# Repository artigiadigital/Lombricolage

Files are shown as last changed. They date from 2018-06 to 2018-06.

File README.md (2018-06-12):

# Lombricolage

## MINI COMPOSTATORE DI FONDI DI CAFFÈ
## ISTRUZIONI PER L'USO E STORIA DEL TAMAGOTCHI DELL'ECONOMIA CIRCOLARE

### CHE COSA È IL LOMBRICOLÀGE?
Il Lombricolàge è un minicompostatore in bioplastica (PLA - Acido Polilattico) stampato in 3D che,
utilizzando alcune specie di lombrichi, è in grado di produrre un compost (vermicompost) di altissima
qualità partendo dai fondi di caffè. La bioplastica è prodotta utilizzando scarti vegetali quindi senza
l'impiego di petrolio e può essere compostata a sua volta, ma a temperature e condizioni diverse da quelle
dell'uso del compostatore che , in condizioni di normale temperatura e umidità, è stabile.
### COME SI USA?
Il Lombricolàge nella sua versione base ha due moduli cilindrici. Si inizia inserendo nel modulo superiore i
lombrichi (almeno per iniziare una decina, meglio ancora per avviare la coltura un quarto in volume di uno
dei due moduli) della specie Eisenia fetida o Eisenia andrei insieme ai fondi di caffè, sbriciolandoli a
mano o con la paletta in dotazione o, nel caso delle cialde, liberandole dall'involucro. Quando il modulo
superiore è pieno, si possono invertire i moduli (spostando il superiore in basso e l'inferiore vuoto in alto).
I fondi di caffè vanno innaffiati quando si seccano in modo che il contenuto sia sempre leggermente
umido, ma mai zuppo. Per innaffiare il contenuto in maniera uniforme potete usare la cupola rovesciata.
### DOVE SI TIENE IL LOMBRICOLÀGE?
I lombrichi Eisenia si trovano a loro agio all'ombra e in un intervallo tra i 13°C e i 25°C, sopravvivono
dagli 0°C ai 35°C seppur riducendo molto la loro attività e quindi il processo di compostaggio del caffè.
Anche la bioplastica con cui è realizzato il Lombricolàge è sensibile al calore e alla luce diretta
continuativa del sole. Se avrete cura della bioplastica, non solo il Lombricolàge non si deformerà, ma i
lombrichi rimarranno in salute. Considerateli un tutt'uno e come se fossero un sistema vivente. I lombrichi
non escono comunque mai dal Lombricolàge poiché per loro è un ambiente ideale, pertanto non abbiate timore: non li troverete in giro per casa.
### IN QUANTO TEMPO SI FORMA IL COMPOST?
Il tempo di compostaggio a regime è variabile a seconda della stagione, e quindi delle temperature, dai 2 ai
4 mesi. Potete constatare che il processo è completato nel momento in cui i fondi di caffè cominciano a
odorare di bosco. Potete rigirare regolarmente il compost con la paletta in dotazione. Anche se ha le punte
appositamente arrotondate, usatela con delicatezza per non ferire i lombrichi.
### E QUANDO IL COMPOST E' PRONTO?
Potete mischiarlo al terriccio per le vostre piante, anche insieme ai lombrichi che continueranno pertanto la
loro azione benefica per le fertilità del suolo anche fuori dal Lombricolàge, ma conservatene sempre un
certo quantitativo per rimetterli nei moduli intermedi e continuare il processo. Se invece desiderate
dividere il compost dai lombrichi per conservarne il maggior numero possibile, potete farlo manualmente
oppure potete rovesciare il contenuto di un modulo all'interno di una piccola vaschetta o barattolo, e
riempire lentamente di acqua fino a lasciare circa 3 centimetri di compost fuori dall'acqua. I lombrichi nel
giro di 10-20 minuti si sposteranno da soli verso la parte emersa. Con la paletta in dotazione, o un
cucchiaio, potete quindi separarli dal materiale sottostante in immersione e riporli nel Lombricolàge. La
parte che rimarrà sotto il pelo dell'acqua sarà un misto di compost, qualche lombrico più pigro a scappare e
acqua. Dividete quindi il compost dall'acqua con un mestolo o filtrandolo. Potete usare il compost e i
lombrichi mischiandoli alla terra dei vasi. L'acqua rimanente, che sarà diventata un liquido scuro, è un
fertilizzante molto potente, quindi non gettatelo: potete usarlo per innaffiare previa ampia diluizione.
### POSSONO CAPITARE INCONVENIENTI ?
Se la superficie superiore del caffè presenta muffe, non preoccupatevi: basta girarlo con la paletta ed
evitare che sia o troppo secco o troppo umido. Può capitare che si formino dei moscerini (neri o bianchi):
non usate assolutamente insetticidi, ma rigirate i fondi di caffè con la paletta, riducete le innaffiature e
all'occorrenza lasciate per qualche giorno il Lombricolàge senza la cupola per farlo asciugare un pochino.
Verificate in ogni caso che la base inferiore non abbia conservato troppa acqua. Anche in questo caso può
essere usata come fertilizzante. Nei mesi più caldi, o in caso di assenza prolungata da casa, potete anche
lasciare un dito di acqua nel serbatoio per evitare che i fondi si secchino troppo. I lombrichi sopravvivono
tranquillamente in vostra assenza fino a circa 3-4 settimane. Prima di partire per più di una settimana
rigirate sempre il contenuto dei moduli intermedi, aggiungete qualche fondo di caffè per fornire nutrimento
e inumidite con acqua. I due moduli sono altamente traspiranti, caratteristica che permette all'ossigeno di
passare attraverso le loro pareti impedendo fenomeni di anossia ai lombrichi e al contenuto organico. La
traspirabilità è permessa dalla porosità dei moduli intermedi. Per tale motivo, in caso in cui si dovessero
sporcare esternamente si consiglia di lavarli subito in modo che non si macchino. Non immergete in acqua
i moduli con il compost perché rischiate anche in questo caso di inzupparne il contenuto che macchierebbe
le pareti dei moduli.
### COME E' NATO IL LOMBRICOLÀGE?
Dopo un corso di autocostruzione di stampante 3D durato un weekend ci siamo trovati come rifiuto decine
e decine di cialde di caffè (quelle in tessuto). Praticando il compostaggio domestico da anni mi sono posto
il problema di come gestire questa potenziale ricchezza organica senza doverla buttare. Avendo appenaacquisito le conoscenze basilari per il disegno CAD e già sperimentato in terrazza il compostaggio dei
fondi di caffè con lombrichi, mi sono chiesto se il processo avesse funzionato anche in un ambiente più
piccolo. Avevo in quel momento una stampante 3D appena assemblata, quale migliore occasione per dare
seguito alla teoria se non provare a realizzare un piccolo compostatore di aspetto gradevole e verificarne il
funzionamento? Dopo un anno di sperimentazione abbiamo visto che i lombrichi Eisenia fetida ed andrei,
anche se nutriti solo a fondi di caffè e in un ambiente molto piccolo (15 cm di diametro e 8 di altezza), non
solo producono un ottimo compost, ma rimangono vitali e fecondi.
### MA IN FONDO NE VALE LA PENA?
Nei soli Stati Uniti si producono 2 milioni di tonnellate all'anno di fondi di caffè che, o vanno in discarica,
o devono essere processate. Con il Lombricolàge potete produrre voi stessi in casa e in ufficio piccoli
quantitativi di compost di altissima qualità per il vostri vasi. Di certo non pensiamo di risolvere con il
Lombricolàge il problema della corretta gestione dei rifiuti urbani, ma anche i piccoli passi sono
importanti. Come è importante sopratutto nei confronti delle nuove generazioni il carattere educativo dei
concetti base dell'economia circolare e dei processi naturali del ciclo dei nutrienti. Il Lombricolàge è di
certo un ottimo ausilio didattico nelle scuole e nelle famiglie. I bambini lo adorano. Provare per credere!
Se volete saperne di più, in fondo a questo documento potete trovare alcune referenze scientifiche relative
al compostaggio del caffè e di altri rifiuti organici.
### POSSO INSERIRE NEL LOMBRICOLÀGE ANCHE ALTRO MATERIALE ORGANICO OLTRE AL CAFFÈ?
Potenzialmente sì, i lombrichi riescono a processare molti tipi di materiale organico, ma si sconsiglia di
usare pasta, pane, agrumi, carne, latticini o comunque materiale oleoso. Inoltre va tenuto in considerazione
che il volume del Lombricolàge è molto ridotto e potrebbero facilmente crearsi squilibri e formazione di
cattivi odori. Potete inserire piccoli quantitativi di carta e residui vegetali: ma non teneteli in superficie. In
ogni caso il funzionamento corretto del Lombricolàge è stato testato finora solo con i fondi di caffè.
### VORREI USARE IL LOMBRICOLÀGE PER COMPOSTARE IL MIO UMIDO DI CASA, NE SONO PREVISTE VERSIONI PIÙ GRANDI?
Si, stiamo lavorando a delle versioni più grandi e le stiamo sperimentando. Per rimanere aggiornati su
eventuali novità potete iscrivervi anche in questo caso alla newsletter di www.lombricolage.eu
### COME POSSO AVERNE UNO?
Il Lombricolàge non è in vendita. I file .stl per la stampa 3D possono essere richiesti dal sito
www.lombricolage.eu. 
Il disegno del Lombricolàge e i file di stampa 3D sono gratuiti, rilasciati sotto
licenza Creative Common BY-NC. 
Potete quindi liberamente stamparli, redistribuirli e modificarli purché
non sia a scopo commerciale e che venga citato l'autore Dario Tamburrano e la provenienza dei file dal sito
www.lombricolage.eu.
Se possedete una stampante 3D potete realizzare da soli il vostro Lombricolàge, anche personalizzandolo, o chiedere a un amico che la possiede o a un service di stampa 3D di realizzarlo per voi. Siamo a vostra disposizione per consigli sulla stampa e per darvi supporto per eventuali difficoltà o domande. Per soddisfare le numerose richieste di coloro che n desiderano una copia, dato che i tempi di stampa complessiva di un Lombricolàge variano dalle 20 alle 36 ore, stiamo valutando alcune opzioni per soddisfare queste richieste. Per essere informati automaticamente su eventuali novità potete iscrivervi alla newsletter sul sito www.lombricolage.eu.

### REFERENZE SCIENTIFICHE SUL COMPOSTAGGIO CON LOMBRICHI (VERMICOMPOSTNG)
A cura dell’EPRS (Servizio di Ricerca del Parlamento Europeo)

The Effects of Varying coffee Ground Amounts on earthworm Eisenia fetida Biomass in Vermicomposting / Sarah
Fink, Lauryn Hong, Izzy Morrison, Yishi Wang, Working paper from Natural Resources and Environment, Michigan State
University, 2012
Vermicomposting of coffee pulp using the earthworm Eiseni fetida: effects on C and N contents and the availability
of nutrients / Orozco, Cegarra, Trujillo, Roig, Biology and Fertlity of Soils [1996, 22(1/2):162- 166] Waste recycling:
Utlization of coffee grounds and kitchen waste in vermicomposting, / Adi, Noor, Bioresource Technology, Volume 100,
Issue 2, January 2009, Pages 1027–1030
Waste recycling: Utilization of coffee grounds and kitchen waste in vermicomposting / Adi, Noor, Bioresource
Technology, Volume 100, Issue 2, January 2009, Pages 1027–1030
Compost and Vermicompost as Amendments Promoting Soil Health / Jack, Thies, Biological Approaches to
Sustainable Soil Systems
Infuence of coffee vermicompost on growth and nutrient quality of greenhouse spinach and feld grown green bell
peppers / April Lorraine Vigardt, Southern Illinois University Carbondale, 2012
Modelling the Processes of Vermicomposting in an Ecological Box – Recognized Critical Points / Contemporary
Problems of Management and Environmental Protecton, No. 9, 2011, Joanna Kostecka, Mariola Garczynska, Grzegorz
Paczka, Janusz Mroczek
Potential utlization of bagasse as feed material for earthworm Eisenia fetida and production of vermicompost / Sartaj
Ahmad Bhat, Jaswinder Singh, Adarsh Pal Vig, Springerplus. 2015; 4: 11
Species-Specific Effects of Epigeic Earthworms on Microbial Community Structure during First Stages of
Decomposition of Organic Matter / Brandon, Lores, Dominguez, PLoS One. 2012
Vermicomposting of food waste: assessing the stability and maturity / Monireh Majlessi, Akbar Eslami, Hossein Najaf
Saleh, Simin Mirshafeean, and Sara Babaii, Iranian J Environ Health Sci Eng. 2012; 9(1): 25
Eisenia fetida (Oligochaeta, Lumbricidae) Actvates Fungal Growth, Triggering Cellulose Decomposition During
Vermicomposting / Aira, Monroy, Domın guez, Microbial Ecology, 2006
Potentiality of Earthworms for Waste Management and in Other Uses – A Review / Sharma, Pradhan, Satya,
Vasudevan, The Journal of American Science. 2005
Vermicomposting of tea leaves waste mixed with cow dung with the help of exotic earthworm Eisenia fetida /
Sarabpal Kaur, Gunsheen Kour and Jaswinder Singh, International Journal of Advanced Research in Biological Sciences,
2014
Vermiculture Technology: Reviving the Dreams of Sir Charles Darwin for Scientific Use of Earthworms in
Sustainable Development Programs / Sinha, Rajiv K. ; Agarwal, Sunita ; Chauhan, Krunal ; Chandran, Vinod ; Soni,
Brijal Kiranbhai, Technology and Investment, August, 2010, Vol.1(3), p.155(18) [Peer Reviewed Journal

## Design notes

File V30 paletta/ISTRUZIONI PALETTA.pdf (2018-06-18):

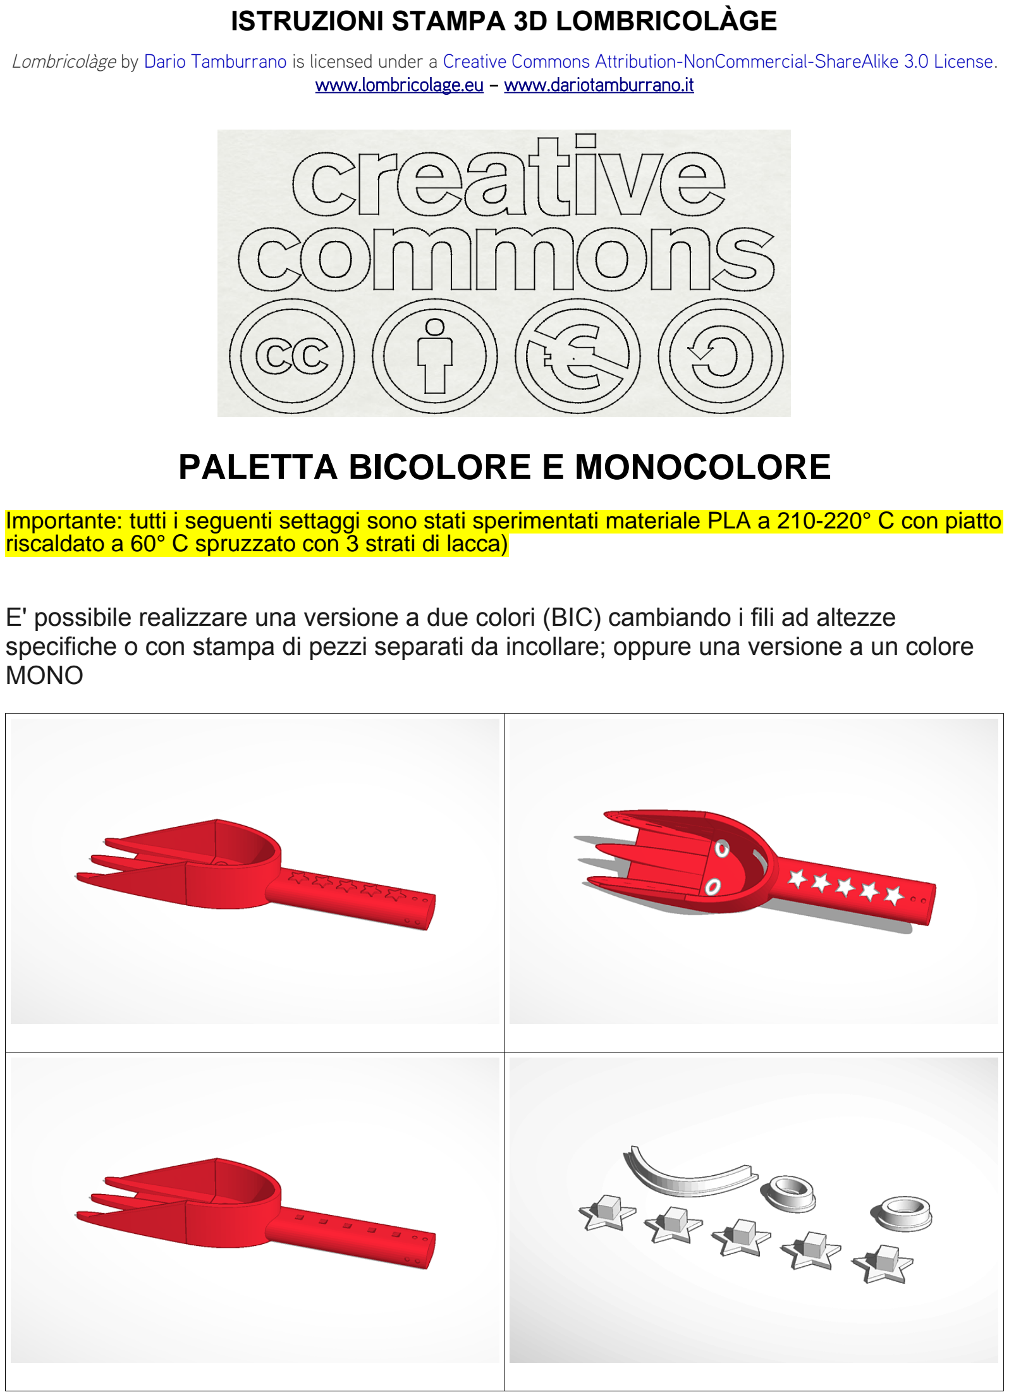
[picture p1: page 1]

ISTRUZIONI STAMPA 3D LOMBRICOLÀGE

Lombricolàge by Dario Tamburrano (http://labs.creativecommons.org/demos/dhtmllicense/www.dariotamburrano.it) is licensed under a Creative Commons Attribution-NonCommercial-ShareAlike 3.0 License. (http://creativecommons.org/licenses/by-nc-sa/3.0/) www.lombricolage.eu – www.dariotamburrano.it

## PALETTA BICOLORE E MONOCOLORE

Importante: tutti i seguenti settaggi sono stati sperimentati materiale PLA a 210-220° C con piatto riscaldato a 60° C spruzzato con 3 strati di lacca)

E' possibile realizzare una versione a due colori (BIC) cambiando i fili ad altezze specifiche o con stampa di pezzi separati da incollare; oppure una versione a un colore MONO

BIColore

Sono due file di stampa, uno per la paletta (bicv30_paletta) e uno per stelline e faccina (bicv30_stelle_faccina_paletta) che si possono incollare con una puntina di artiglio (tra gli alloggiamenti nella paletta e i pezzi abbiamo lasciato uno spazio di un mm per evitare che la colla strabordi)

MONOcolore

La versione mono (monov30_paletta) si può stampare facoltativamente a un solo colore o anche a due colori cambiando manualmente il filo. Ad esempio se si vuole fare rossa e bianca si parte con il rosso, per fare la faccina bianca si sostituisce il bianco a 3 mm di altezza fino a 3.80 mm. A 3.80 mm si rimette il rosso fino a 11.80 mm alla quale altezza per fare le stelline bianche si mette il bianco fino a 12.60 per poi passare al rosso.

Chiaramente per quanto riguarda la scelta dei colori si è liberi di cambiarli

REGOLAZIONE PER INSERIMENTO IN ALLOGGIAMENTO

Le palette sono dotate di piccoli spessori, in pratica dei puntini ai lati e sopra la parte iniziale del manico. Sono stati appositamente disegnati affinché si possa ottimizzare e regolare l’inserimento nell’apposito alloggiamento della base serbatoio: se vi sono difficoltà perché il manico entra con difficoltà, potete tagliare i puntini con un taglierino.

FILE INCLUSI PER OGNI OGGETTO

- Cartella STL: contiene i file .stl
- Cartella ISTRUZIONI: i VALORI SETTAGGI ovvero gli screenshot dei settaggi per cura ove si possono estrapolare i valori come layer heigt, speed, spessore pareti, retrazione etc per altre macchine; i GCODE E PROFILI ove si trovano per chi ne avesse bisogno i profili .ini per Cura e i .gcode per ultimaker 2+ già pronti

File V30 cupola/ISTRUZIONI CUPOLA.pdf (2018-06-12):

ISTRUZIONI STAMPA 3D LOMBRICOLÀGE

Lombricolàge by Dario Tamburrano (http://labs.creativecommons.org/demos/dhtmllicense/www.dariotamburrano.it) is licensed under a Creative Commons Attribution-NonCommercial-ShareAlike 3.0 License. (http://creativecommons.org/licenses/by-nc-sa/3.0/) www.lombricolage.eu – www.dariotamburrano.it

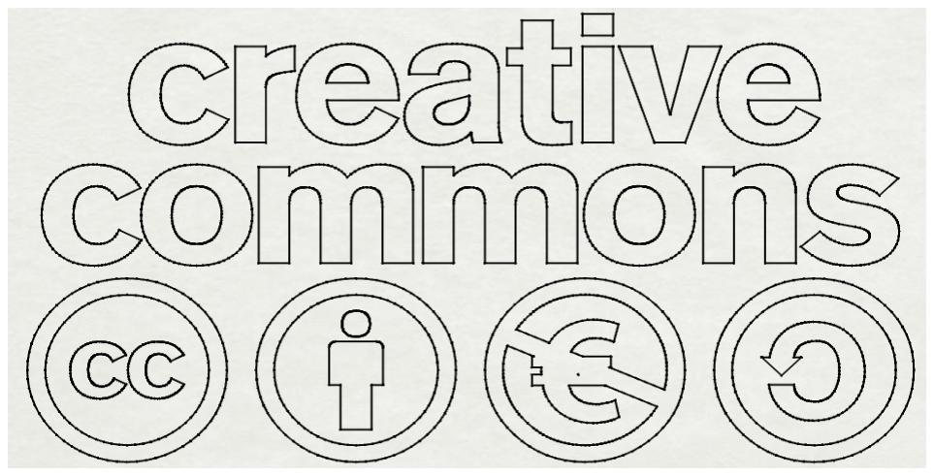
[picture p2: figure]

## CUPOLA (e frecce)

Importante: tutti i seguenti settaggi sono stati sperimentati materiale PLA a 210-220° C con piatto riscaldato a 60° C spruzzato con 3 strati di lacca)

MONOCOLORE

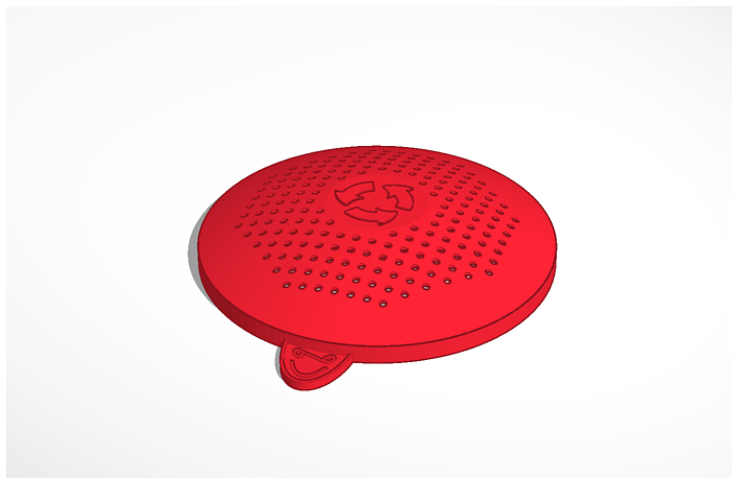
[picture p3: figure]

La versione mono (monov30_cupola) si può stampare facoltativamente a un solo colore o anche a due colori cambiando manualmente il filo: ad esempio se si vuole fare rossa e bianca si parte con il rosso, poi per fare la faccina bianca si sostituisce con il bianco a 3 mm di altezza fino a 26.40 mm alla quale altezza si rimette il rosso per fare le frecce rosse.

BICOLORE

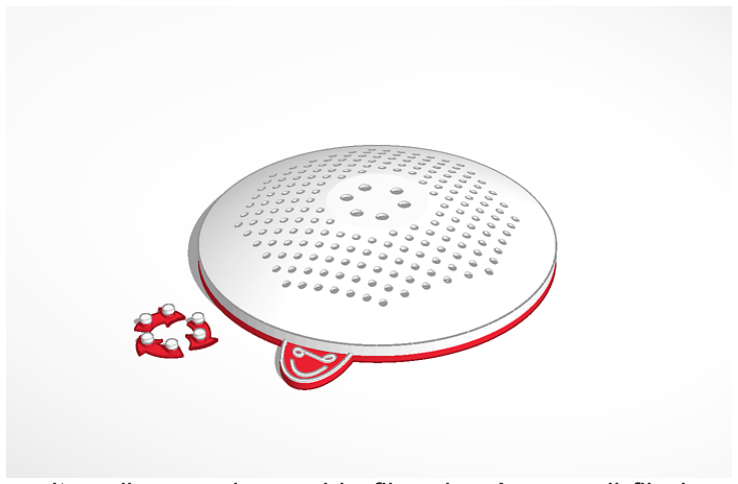
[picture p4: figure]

In alternativa per evitare il secondo cambio filo, si può usare il file in cui le frecce sono poste separate e girate sul piatto (bicv30_cupola_e_frecce). Iniziando con il rosso, si può sostituire con il bianco a 3 mm di altezza

I pezzi ottenuti possono essere assemblati con un po’ di colla ad esempio artiglio. Si possono anche stampare separatamente (bicv30_solo_cupola e bicv30_frecce)

Chiaramente per quanto riguarda la scelta dei colori si è liberi di cambiarli

FILE INCLUSI PER OGNI OGGETTO

- Cartella STL: contiene i file .stl
- Cartella ISTRUZIONI: i VALORI SETTAGGI ovvero gli screenshot dei settaggi per cura ove si possono estrapolare i valori come layer heigt, speed, spessore pareti, retrazione etc per altre macchine; i GCODE E PROFILI ove si trovano per chi ne avesse bisogno i profili .ini per Cura e i .gcode per ultimaker 2+ già pronti

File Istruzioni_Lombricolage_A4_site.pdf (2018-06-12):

# LOMBRICOLÀGE

### MINI COMPOSTATORE DI FONDI DI CAFFÈ

ISTRUZIONI PER L'USO E STORIA DEL TAMAGOTCHI DELL'ECONOMIA CIRCOLARE

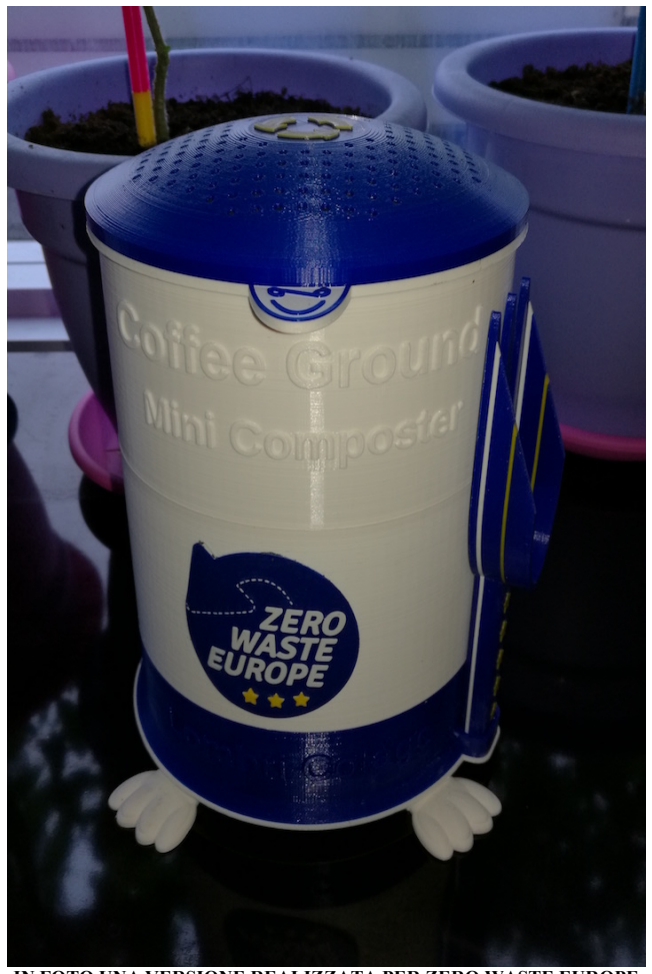
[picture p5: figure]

IN FOTO UNA VERSIONE REALIZZATA PER ZERO WASTE EUROPE

### CHE COSA È IL LOMBRICOLÀGE?

Il Lombricolàge è un minicompostatore in bioplastica (PLA - Acido Polilattico) stampato in 3D che, utilizzando alcune specie di lombrichi, è in grado di produrre un compost (vermicompost) di altissima qualità partendo dai fondi di caffè. La bioplastica è prodotta utilizzando scarti vegetali quindi senza l'impiego di petrolio e può essere compostata a sua volta, ma a temperature e condizioni diverse da quelle dell'uso del compostatore che , in condizioni di normale temperatura e umidità, è stabile.

### COME SI USA?

Il Lombricolàge nella sua versione base ha due moduli cilindrici. Si inizia inserendo nel modulo superiore i lombrichi (almeno per iniziare una decina, meglio ancora per avviare la coltura un quarto in volume di uno
dei due moduli) della specie Eisenia fetida | o Eisenia andrei | insieme ai fondi di caffè, sbriciolandoli a
mano o con la paletta in dotazione o, nel caso delle cialde, liberandole dall'involucro. Quando il modulo superiore è pieno, si possono invertire i moduli (spostando il superiore in basso e l'inferiore vuoto in alto). I fondi di caffè vanno innaffiati quando si seccano in modo che il contenuto sia sempre leggermente umido, ma mai zuppo. Per innaffiare il contenuto in maniera uniforme potete usare la cupola rovesciata.

### DOVE SI TIENE IL LOMBRICOLÀGE?

I lombrichi Eisenia si trovano a loro agio all'ombra e in un intervallo tra i 13°C e i 25°C, sopravvivono dagli 0°C ai 35°C seppur riducendo molto la loro attività e quindi il processo di compostaggio del caffè. Anche la bioplastica con cui è realizzato il Lombricolàge è sensibile al calore e alla luce diretta continuativa del sole. Se avrete cura della bioplastica, non solo il Lombricolàge non si deformerà, ma i lombrichi rimarranno in salute. Considerateli un tutt'uno e come se fossero un sistema vivente. I lombrichi non escono comunque mai dal Lombricolàge poiché per loro è un ambiente ideale, pertanto non abbiate timore: non li troverete in giro per casa.

### IN QUANTO TEMPO SI FORMA IL COMPOST?

Il tempo di compostaggio a regime è variabile a seconda della stagione, e quindi delle temperature, dai 2 ai 4 mesi. Potete constatare che il processo è completato nel momento in cui i fondi di caffè cominciano a odorare di bosco. Potete rigirare regolarmente il compost con la paletta in dotazione. Anche se ha le punte appositamente arrotondate, usatela con delicatezza per non ferire i lombrichi.

### E QUANDO IL COMPOST E' PRONTO?

Potete mischiarlo al terriccio per le vostre piante, anche insieme ai lombrichi che continueranno pertanto la loro azione benefica per le fertilità del suolo anche fuori dal Lombricolàge, ma conservatene sempre un certo quantitativo per rimetterli nei moduli intermedi e continuare il processo. Se invece desiderate dividere il compost dai lombrichi per conservarne il maggior numero possibile, potete farlo manualmente oppure potete rovesciare il contenuto di un modulo all'interno di una piccola vaschetta o barattolo, e riempire lentamente di acqua fino a lasciare circa 3 centimetri di compost fuori dall'acqua. I lombrichi nel giro di 10-20 minuti si sposteranno da soli verso la parte emersa. Con la paletta in dotazione, o un cucchiaio, potete quindi separarli dal materiale sottostante in immersione e riporli nel Lombricolàge. La parte che rimarrà sotto il pelo dell'acqua sarà un misto di compost, qualche lombrico più pigro a scappare e acqua. Dividete quindi il compost dall'acqua con un mestolo o filtrandolo. Potete usare il compost e i lombrichi mischiandoli alla terra dei vasi. L'acqua rimanente, che sarà diventata un liquido scuro, è un fertilizzante molto potente, quindi non gettatelo: potete usarlo per innaffiare previa ampia diluizione.

### POSSONO CAPITARE INCONVENIENTI?

Se la superficie superiore del caffè presenta muffe, non preoccupatevi: basta girarlo con la paletta ed evitare che sia o troppo secco o troppo umido. Può capitare che si formino dei moscerini (neri o bianchi): non usate assolutamente insetticidi, ma rigirate i fondi di caffè con la paletta, riducete le innaffiature e all'occorrenza lasciate per qualche giorno il Lombricolàge senza la cupola per farlo asciugare un pochino. Verificate in ogni caso che la base inferiore non abbia conservato troppa acqua. Anche in questo caso può essere usata come fertilizzante. Nei mesi più caldi, o in caso di assenza prolungata da casa, potete anche lasciare un dito di acqua nel serbatoio per evitare che i fondi si secchino troppo. I lombrichi sopravvivono tranquillamente in vostra assenza fino a circa 3-4 settimane. Prima di partire per più di una settimana rigirate sempre il contenuto dei moduli intermedi, aggiungete qualche fondo di caffè per fornire nutrimento e inumidite con acqua. I due moduli sono altamente traspiranti, caratteristica che permette all'ossigeno di passare attraverso le loro pareti impedendo fenomeni di anossia ai lombrichi e al contenuto organico. La traspirabilità è permessa dalla porosità dei moduli intermedi. Per tale motivo, in caso in cui si dovessero sporcare esternamente si consiglia di lavarli subito in modo che non si macchino. Non immergete in acqua i moduli con il compost perché rischiate anche in questo caso di inzupparne il contenuto che macchierebbe le pareti dei moduli.

### COME E' NATO IL LOMBRICOLÀGE?

Dopo un corso di autocostruzione di stampante 3D durato un weekend ci siamo trovati come rifiuto decine e decine di cialde di caffè (quelle in tessuto). Praticando il compostaggio domestico da anni mi sono posto il problema di come gestire questa potenziale ricchezza organica senza doverla buttare. Avendo appena acquisito le conoscenze basilari per il disegno CAD e già sperimentato in terrazza il compostaggio dei fondi di caffè con lombrichi, mi sono chiesto se il processo avesse funzionato anche in un ambiente più piccolo. Avevo in quel momento una stampante 3D appena assemblata, quale migliore occasione per dare seguito alla teoria se non provare a realizzare un piccolo compostatore di aspetto gradevole e verificarne il funzionamento? Dopo un anno di sperimentazione abbiamo visto che i lombrichi Eisenia fetida ed andrei, anche se nutriti solo a fondi di caffè e in un ambiente molto piccolo (15 cm di diametro e 8 di altezza), non solo producono un ottimo compost, ma rimangono vitali e fecondi.

### MA IN FONDO NE VALE LA PENA?

Nei soli Stati Uniti si producono 2 milioni di tonnellate all'anno di fondi di caffè che, o vanno in discarica, o devono essere processate. Con il Lombricolàge potete produrre voi stessi in casa e in ufficio piccoli quantitativi di compost di altissima qualità per il vostri vasi. Di certo non pensiamo di risolvere con il Lombricolàge il problema della corretta gestione dei rifiuti urbani, ma anche i piccoli passi sono importanti. Come è importante sopratutto nei confronti delle nuove generazioni il carattere educativo dei concetti base dell'economia circolare e dei processi naturali del ciclo dei nutrienti. Il Lombricolàge è di certo un ottimo ausilio didattico nelle scuole e nelle famiglie. I bambini lo adorano. Provare per credere! Se volete saperne di più, in fondo a questo documento potete trovare alcune referenze scientifiche relative al compostaggio del caffè e di altri rifiuti organici.

### POSSO INSERIRE NEL LOMBRICOLÀGE ANCHE ALTRO MATERIALE ORGANICO OLTRE AL CAFFÈ?

Potenzialmente sì, i lombrichi riescono a processare molti tipi di materiale organico, ma si sconsiglia di usare pasta, pane, agrumi, carne, latticini o comunque materiale oleoso. Inoltre va tenuto in considerazione che il volume del Lombricolàge è molto ridotto e potrebbero facilmente crearsi squilibri e formazione di cattivi odori. Potete inserire piccoli quantitativi di carta e residui vegetali: ma non teneteli in superficie. In ogni caso il funzionamento corretto del Lombricolàge è stato testato finora solo con i fondi di caffè.

### VORREI USARE IL LOMBRICOLÀGE PER COMPOSTARE IL MIO UMIDO DI CASA, NE SONO PREVISTE VERSIONI PIÙ GRANDI?

Si, stiamo lavorando a delle versioni più grandi e le stiamo sperimentando. Per rimanere aggiornati su eventuali novità potete iscrivervi anche in questo caso alla newsletter di www.lombricolage.eu

### COME POSSO AVERNE UNO?

Il Lombricolàge non è in vendita. I file .stl per la stampa 3D possono essere richiesti dal sito www.lombricolage.eu. Il disegno del Lombricolàge e i file di stampa 3D sono gratuiti, rilasciati sotto licenza Creative Common BY-NC. Potete quindi liberamente stamparli, redistribuirli e modificarli purché non sia a scopo commerciale e che venga citato l'autore Dario Tamburrano e la provenienza dei file dal sito www.lombricolage.eu. Se possedete una stampante 3D potete realizzare da soli il vostro Lombricolàge, anche personalizzandolo, o chiedere a un amico che la possiede o a un service di stampa 3D di realizzarlo per voi. Siamo a vostra disposizione per consigli sulla stampa e per darvi supporto per eventuali difficoltà o domande. Per soddisfare le numerose richieste di coloro che ne desiderano una copia, dato che i tempi di stampa complessiva di un Lombricolàge variano dalle 20 alle 36 ore, stiamo valutando alcune opzioni per soddisfare queste richieste. Per essere informati automaticamente su eventuali novità potete iscrivervi alla newsletter sul sito www.lombricolage.eu.

REFERENZE SCIENTIFICHE SUL COMPOSTAGGIO CON LOMBRICHI (VERMICOMPOSTNG)

A cura dell’EPRS (http://www.europarl.europa.eu/atyourservice/it/20150201PVL00031/Servizio-Ricerca-del-Parlamento-europeo) (Servizio di Ricerca del Parlamento Europeo)

- The Effects of Varying coffee Ground Amounts on earthworm Eisenia fetida Biomass in Vermicomposting (https://deepblue.lib.umich.edu/handle/2027.42/96207) / Sarah Fink, Lauryn Hong, Izzy Morrison, Yishi Wang, Working paper from Natural Resources and Environment, Michigan State University, 2012
- Vermicomposting of coffee pulp using the earthworm Eiseni fetida: effects on C and N contents and the availability of nutrients (http://europepmc.org/abstract/AGR/IND20544360) / Orozco, Cegarra, Trujillo, Roig, Biology and Fertlity of Soils [1996, 22(1/2):162- 166] Waste recycling: Utlization of coffee grounds and kitchen waste in vermicomposting, / Adi, Noor, Bioresource Technology, Volume 100, Issue 2, January 2009, Pages 1027–1030
- Waste recycling: Utilization of coffee grounds and kitchen waste in vermicomposting (http://repository.um.edu.my/86680/1/Waste%20recycling%20-%20Utilization%20of%20coffee%20grounds%20and%20kitchen%20waste%20in%20vermicomposting.pdf) / Adi, Noor, Bioresource Technology, Volume 100, Issue 2, January 2009, Pages 1027–1030
- Compost and Vermicompost as Amendments Promoting Soil Health (https://www.researchgate.net/publication/255702142_Compost_and_Vermicompost_as_Amendments_Promoting_Soil_Health) / Jack, Thies, Biological Approaches to Sustainable Soil Systems
- Infuence of coffee vermicompost on growth and nutrient quality of greenhouse spinach and feld grown green bell peppers (http://opensiuc.lib.siu.edu/cgi/viewcontent.cgi?article=1926&context=theses) / April Lorraine Vigardt, Southern Illinois University Carbondale, 2012
- Modelling the Processes of Vermicomposting in an Ecological Box – Recognized Critical Points (http://www.uwm.edu.pl/environ/vol09/vol09_chapter10.pdf) / Contemporary Problems of Management and Environmental Protecton, No. 9, 2011, Joanna Kostecka, Mariola Garczynska, Grzegorz Paczka, Janusz Mroczek
- Potential utlization of bagasse as feed material for earthworm (http://www.ncbi.nlm.nih.gov/pmc/articles/PMC4302158/) Eisenia fetida and production of vermicompost / Sartaj Ahmad Bhat, Jaswinder Singh, Adarsh Pal Vig, Springerplus. 2015; 4: 11
- Species-Specific Effects of Epigeic Earthworms on Microbial Community Structure during First Stages of Decomposition of Organic Matter (http://pubmedcentralcanada.ca/pmcc/articles/PMC3283695/) / Brandon, Lores, Dominguez, PLoS One. 2012
- Vermicomposting of food waste: assessing the stability and maturity (http://pubmedcentralcanada.ca/pmcc/articles/PMC3599696/) / Monireh Majlessi, Akbar Eslami, Hossein Najaf Saleh, Simin Mirshafeean, and Sara Babaii, Iranian J Environ Health Sci Eng. 2012; 9(1): 25
- Eisenia fetida (Oligochaeta, Lumbricidae) Actvates Fungal Growth, Triggering Cellulose Decomposition During Vermicomposting (https://www.researchgate.net/publication/6845172_Eisenia_fetida_Oligochaeta_Lumbricidae_Activates_Fungal_Growth_Triggering_Cellulose_Decomposition_During_Verm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) / Aira, Monroy, Domın guez, Microbial Ecology, 2006
- Potentiality of Earthworms for Waste Management and in Other Uses – A Review (https://www.google.com/url?rct=j&q=&esrc=s&cd=13&cad=rja&uact=8&bvm=bv.104317490,d.d2s) / Sharma, Pradhan, Satya, Vasudevan, The Journal of American Science. 2005
- Vermicomposting of tea leaves waste mixed with cow dung with the help of exotic earthworm Eisenia fetida (http://pubmedcentralcanada.ca/pmcc/articles/PMC3599696/) / Sarabpal Kaur, Gunsheen Kour and Jaswinder Singh, International Journal of Advanced Research in Biological Sciences, 2014
- Vermiculture Technology: Reviving the Dreams of Sir Charles Darwin for Scientific Use of Earthworms in Sustainable Development Programs (http://mlplus.hosted.exlibrisgroup.com/primo_library/libweb/action/display.do?frbrVersion=2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) / Sinha, Rajiv K. ; Agarwal, Sunita ; Chauhan, Krunal ; Chandran, Vinod ; Soni, Brijal Kiranbhai, Technology and Investment, August, 2010, Vol.1(3), p.155(18) [Peer Reviewed Journal]

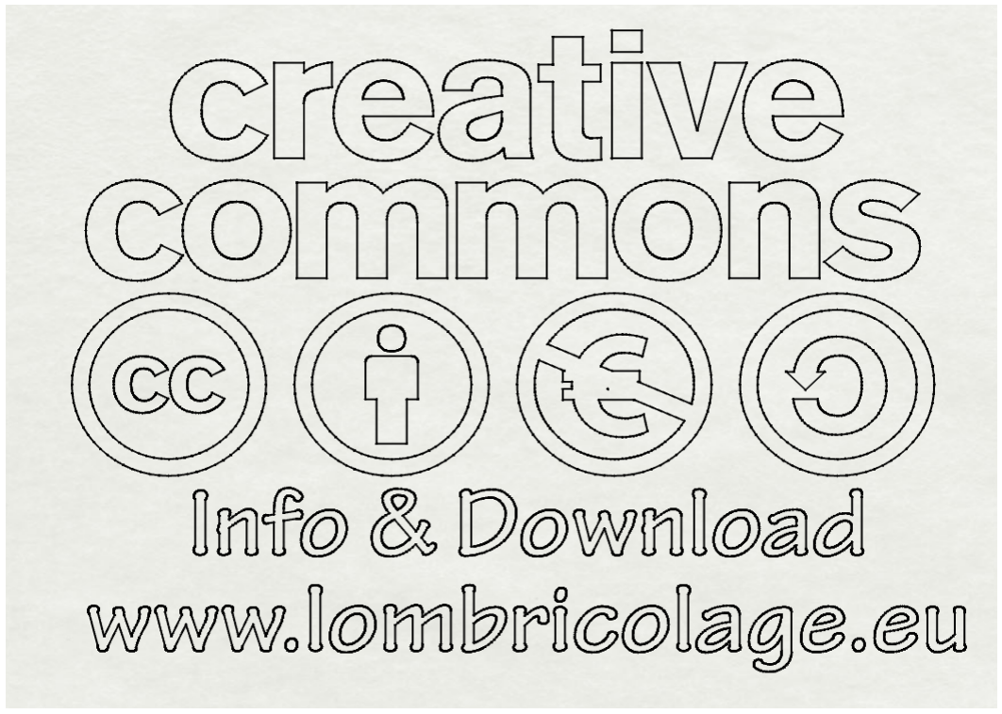
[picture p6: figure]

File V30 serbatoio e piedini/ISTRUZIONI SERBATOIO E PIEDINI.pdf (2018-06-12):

ISTRUZIONI STAMPA 3D LOMBRICOLÀGE

Lombricolàge by Dario Tamburrano (http://labs.creativecommons.org/demos/dhtmllicense/www.dariotamburrano.it) is licensed under a Creative Commons Attribution-NonCommercial-ShareAlike 3.0 License. (http://creativecommons.org/licenses/by-nc-sa/3.0/) www.lombricolage.eu – www.dariotamburrano.it

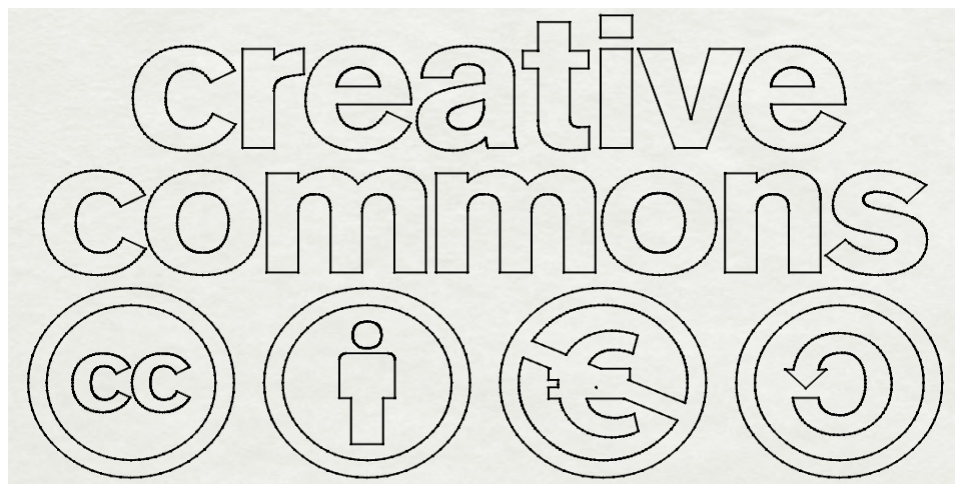
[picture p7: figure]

## SERBATOIO E PIEDINI

Importante: tutti i seguenti settaggi sono stati sperimentati materiale PLA a 210-220° C con piatto riscaldato a 60° C spruzzato con 3 strati di lacca)

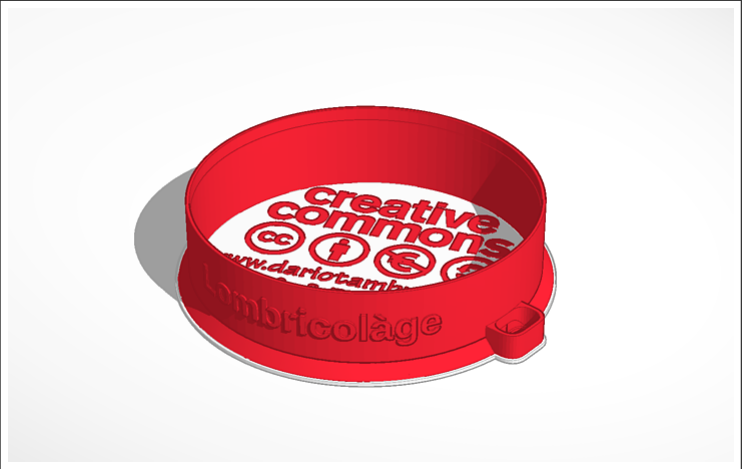
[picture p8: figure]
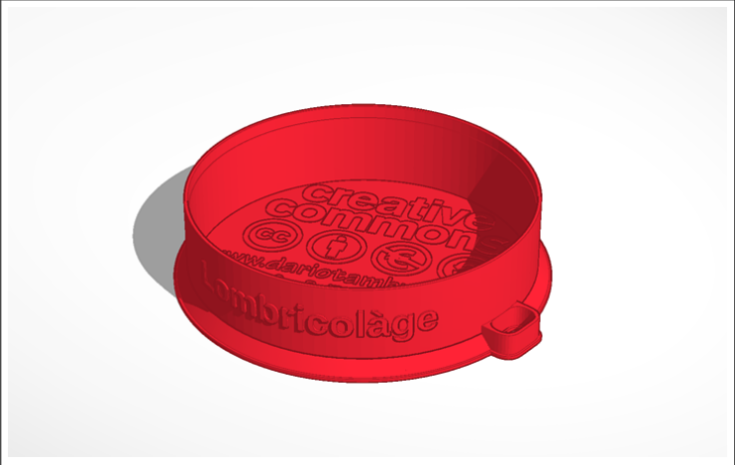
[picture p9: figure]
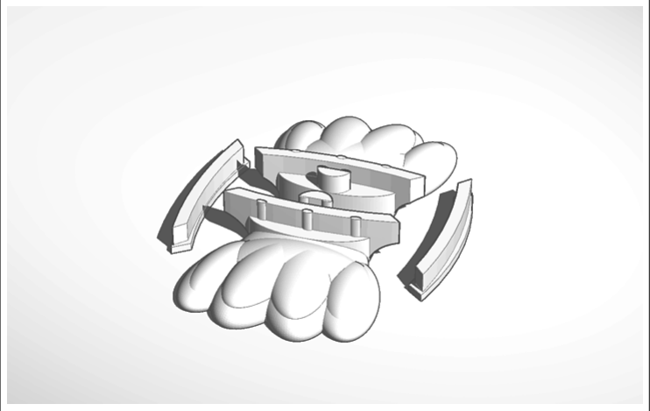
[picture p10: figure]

Il serbatoio si può stampare facoltativamente a un solo colore o anche a due colori cambiando manualmente il filo: ad esempio se si vuole fare con un filo bianco all’esterno e all’interno il fondo bianco con scritte rosse si parte con il bianco e a 1.6 mm di altezza si sostituisce con il rosso. Chiaramente per quanto riguarda la scelta dei colori si è liberi di cambiarli

I piedini sono di due tipi: per colla o per accendino. Scaldando con l’accendino la parte superiore del piedino o zampetta fino a quasi fusione e inserendoli rapidamente nell’alloggiamento. L’operazione con l’accendino, sebbene li renda assai stabili, è abbastanza complicata, si consiglia l’uso della colla (tipo artiglio o bostik).

Il serbatoio, per evitare deformazioni e distacchi dal piano in sede di stampa, è preferibile che venga realizzato usando la funzione brim come da screenshot settaggi allegati. Per la rifinitura usare taglierino e carta vetrata o spugnette abrasive di grana decrescente.

Una volta rifinito è bene trattarlo sia all'interno che all'esterno con due mani di impregnante per legno trasparente all'acqua diluito in modo che possa penetrare nelle porosità della stampa.

FILE INCLUSI PER OGNI OGGETTO

- Cartella STL: contiene i file .stl
- Cartella ISTRUZIONI: i VALORI SETTAGGI ovvero gli screenshot dei settaggi per cura ove si possono estrapolare i valori come layer heigt, speed, spessore pareti, retrazione etc per altre macchine; i GCODE E PROFILI ove si trovano per chi ne avesse bisogno i profili .ini per Cura e i .gcode per ultimaker 2+ già pronti

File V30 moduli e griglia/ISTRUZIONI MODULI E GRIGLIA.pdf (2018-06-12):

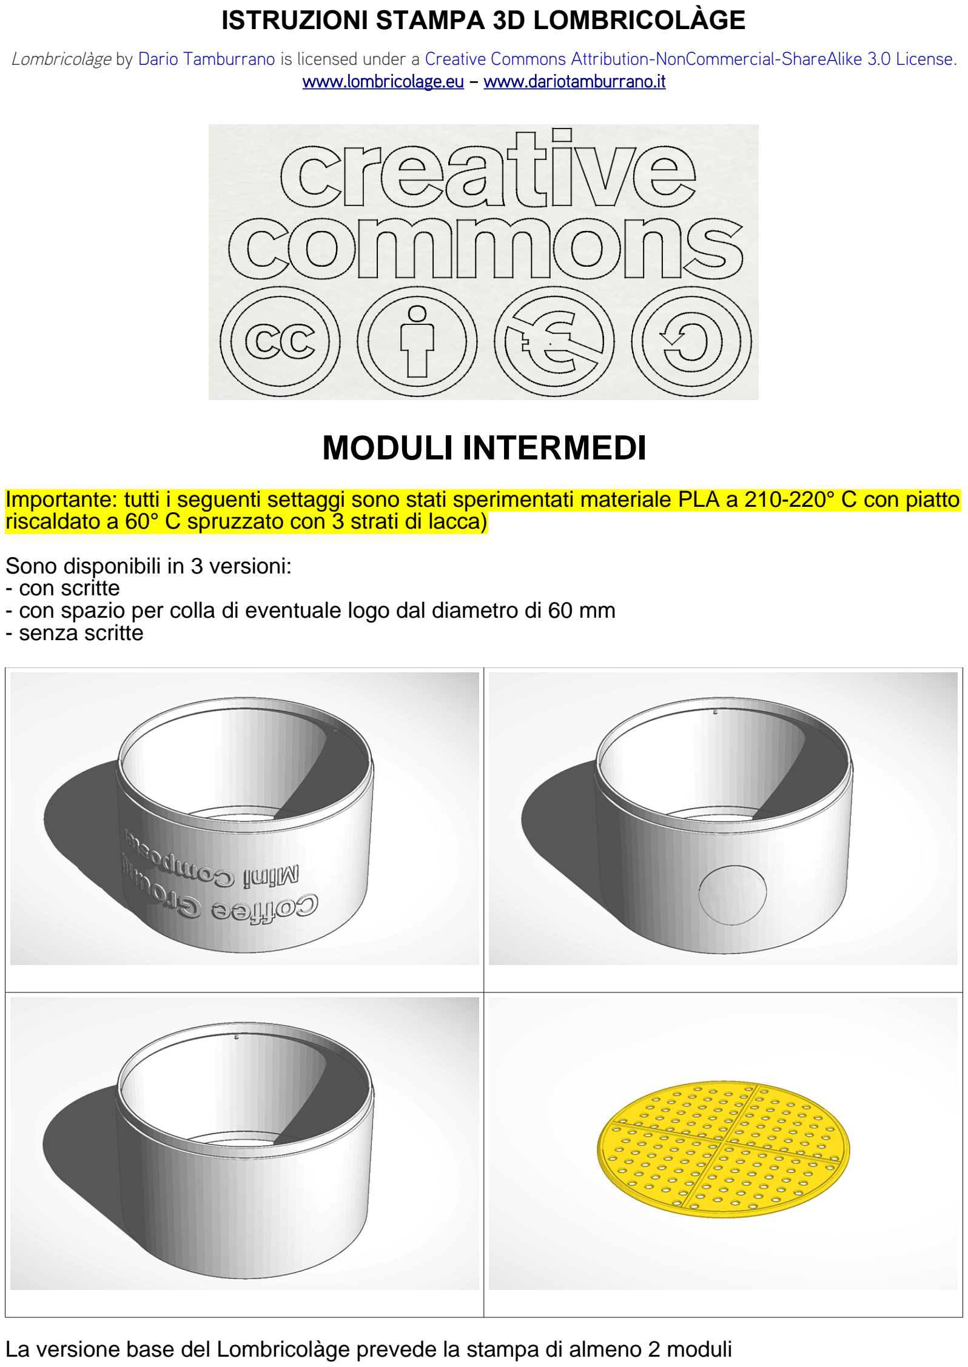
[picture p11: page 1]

ISTRUZIONI STAMPA 3D LOMBRICOLÀGE

Lombricolàge by Dario Tamburrano (http://labs.creativecommons.org/demos/dhtmllicense/www.dariotamburrano.it) is licensed under a Creative Commons Attribution-NonCommercial-ShareAlike 3.0 License. (http://creativecommons.org/licenses/by-nc-sa/3.0/) www.lombricolage.eu – www.dariotamburrano.it

## MODULI INTERMEDI

Importante: tutti i seguenti settaggi sono stati sperimentati materiale PLA a 210-220° C con piatto riscaldato a 60° C spruzzato con 3 strati di lacca)
Sono disponibili in 3 versioni:
- con scritte
- con spazio per colla di eventuale logo dal diametro di 60 mm
- senza scritte

La versione base del Lombricolàge prevede la stampa di almeno 2 moduli

Vengono stampati rovesciati per evitare, a livello dello scalino che permette l’incastro di più moduli, la necessità di supporti in fase di stampa o imprecisioni. Può accadere che la stampa dei primi livelli porti ad avere una parete leggermente più larga che impedisce o rende poco agevole l’inserimento del modulo successivo. E’ sufficiente passare con la lama di un taglierino e grattare la superficie interna (corrispondente ai livelli che sono a contatto con il piano di stampa)
GRIGLIE
Per ogni modulo va stampata una griglia che va inserita nel modulo con la parte più stretta e la croce verso l’alto. Flettendo la griglia in corrispondenza degli scalini interni al modulo si potrà bloccarla in posizione

FILE INCLUSI PER OGNI OGGETTO

- Cartella STL: contiene i file .stl
- Cartella ISTRUZIONI: i VALORI SETTAGGI ovvero gli screenshot dei settaggi per cura ove si possono estrapolare i valori come layer heigt, speed, spessore pareti, retrazione etc per altre macchine; i GCODE E PROFILI ove si trovano per chi ne avesse bisogno i profili .ini per Cura e i .gcode per ultimaker 2+ già pronti

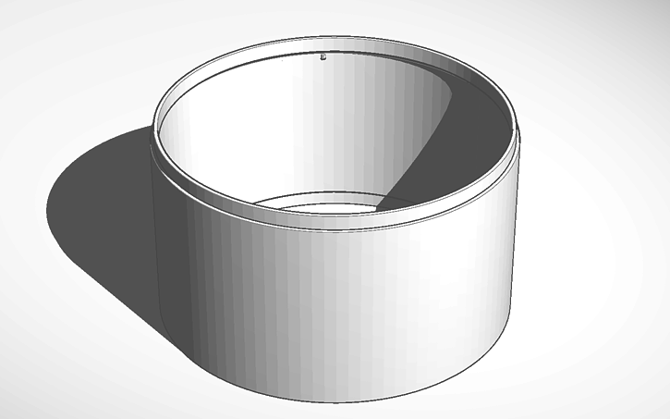
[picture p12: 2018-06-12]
V30 moduli e griglia/v30_modulo_noscritte.png

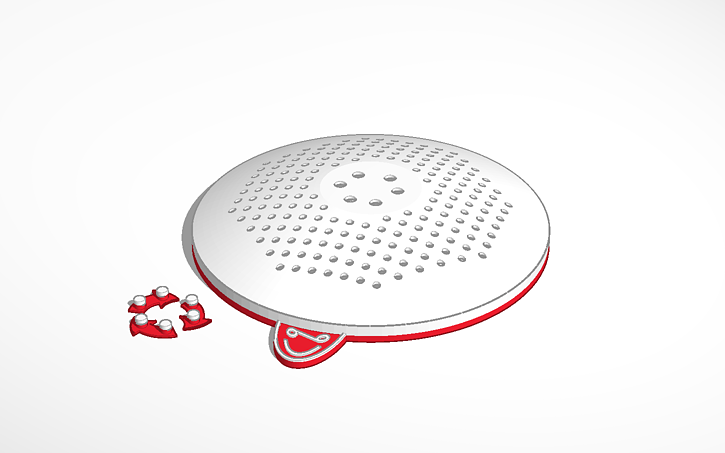
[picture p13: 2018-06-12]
V30 cupola/bicv30_cupola_e_frecce.png

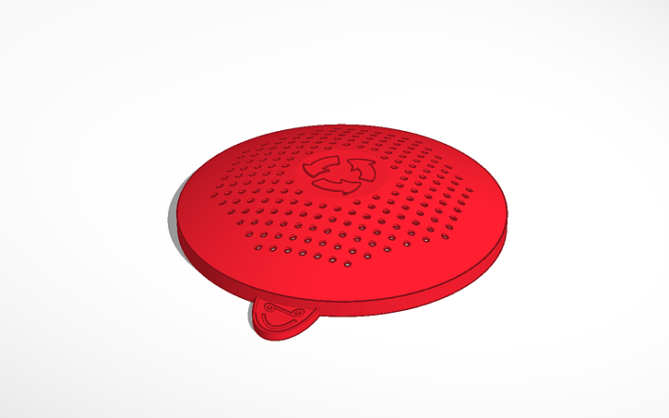
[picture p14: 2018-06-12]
V30 cupola/monov30_cupola (immagine).png

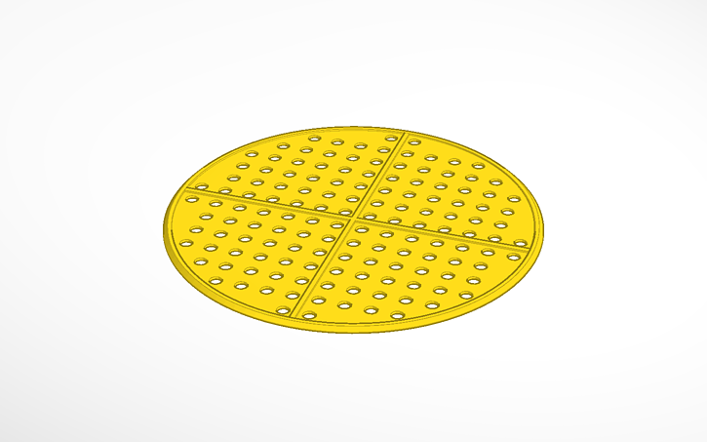
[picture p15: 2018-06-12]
V30 moduli e griglia/v30_griglia.png

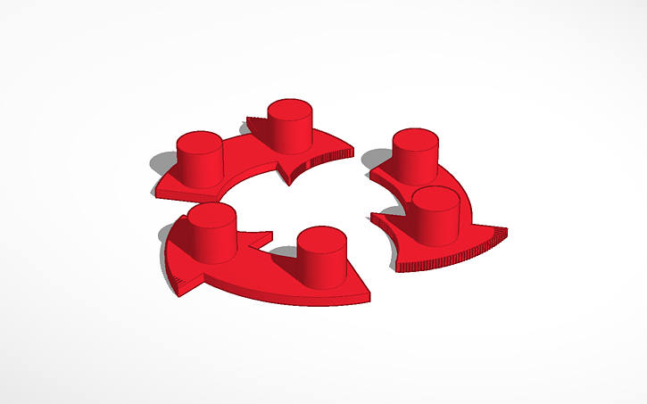
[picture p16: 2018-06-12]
V30 cupola/v30_frecce (immagine).png

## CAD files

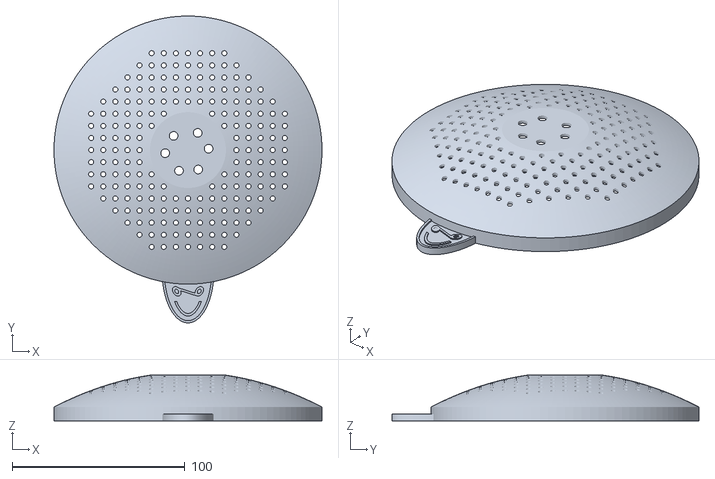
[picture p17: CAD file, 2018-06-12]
V30 cupola/stl/bicv30_solo_cupola.stl
155.0 x 177.5 x 26.4

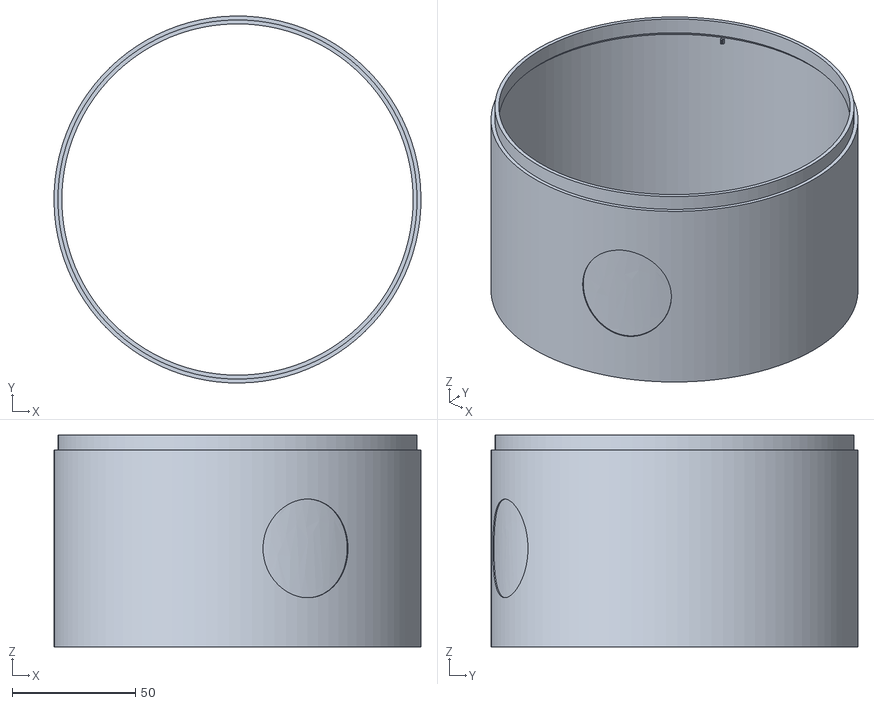
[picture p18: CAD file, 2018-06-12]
V30 moduli e griglia/stl/v30_modulo_logo.stl
149.0 x 149.0 x 86.0

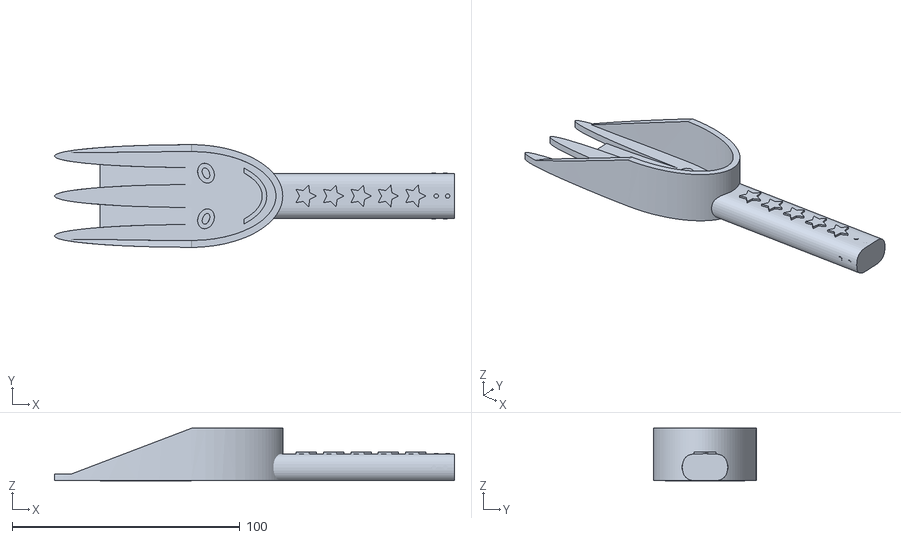
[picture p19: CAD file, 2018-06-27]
V30 paletta/monov30_paletta.stl
175.5 x 45.1 x 23.0

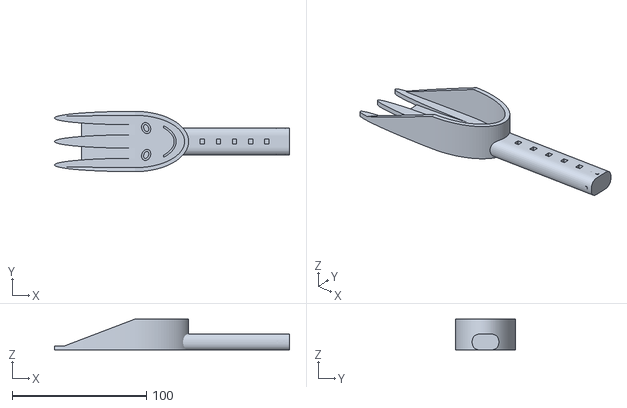
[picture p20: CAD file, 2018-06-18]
V30 paletta/stl/bicv30_paletta.stl
175.2 x 45.0 x 23.0

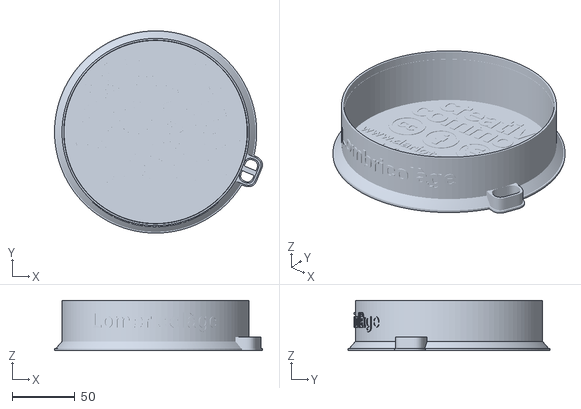
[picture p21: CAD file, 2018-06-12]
V30 serbatoio e piedini/stl/v30_serbatoio.stl
165.6 x 161.0 x 40.0

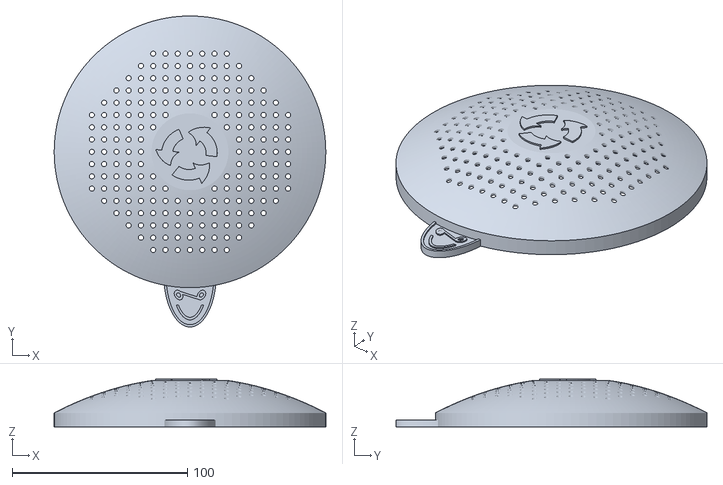
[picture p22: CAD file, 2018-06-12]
V30 cupola/stl/monov30_cupola.stl
155.0 x 177.5 x 27.2

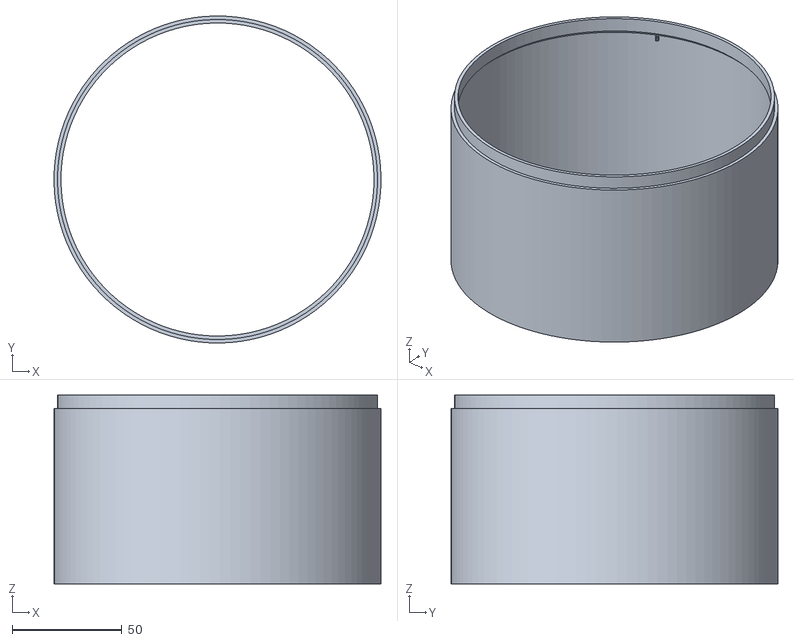
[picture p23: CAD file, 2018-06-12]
V30 moduli e griglia/stl/v30_modulo_no_scritte.stl
149.0 x 149.0 x 86.0

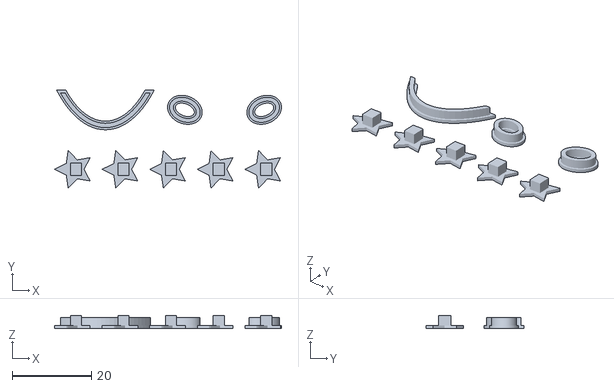
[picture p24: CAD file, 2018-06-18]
V30 paletta/stl/bicv30_stelle_faccina_paletta_colla.stl
57.2 x 24.8 x 3.30

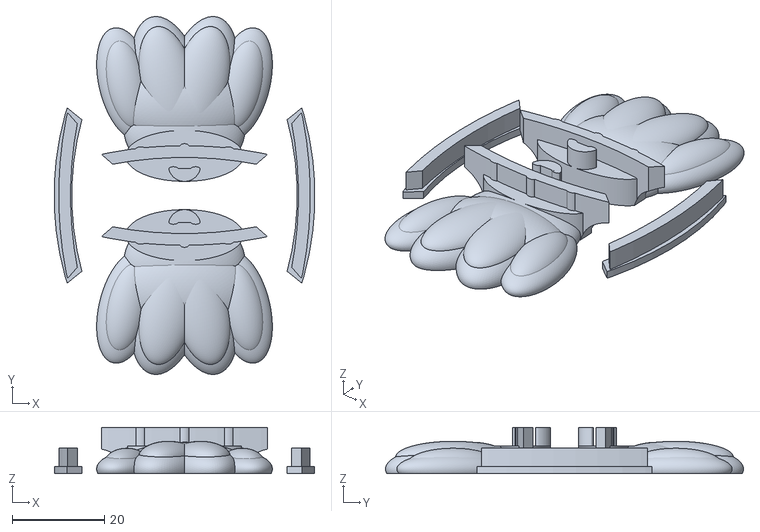
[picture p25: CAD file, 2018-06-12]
V30 serbatoio e piedini/stl/v30_accendino_set_zampe_e_piedini.stl
56.5 x 77.7 x 10.0

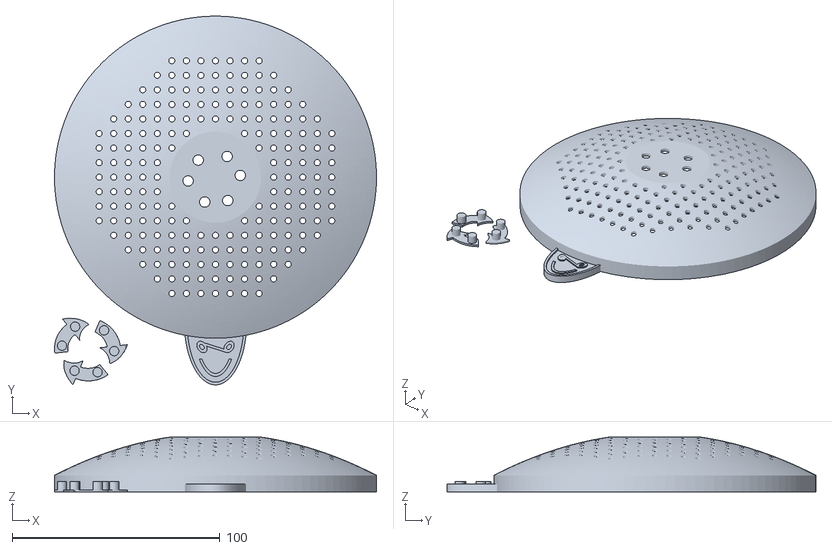
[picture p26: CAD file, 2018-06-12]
V30 cupola/stl/bicv30_cupola_e_frecce.stl
155.0 x 177.5 x 26.4

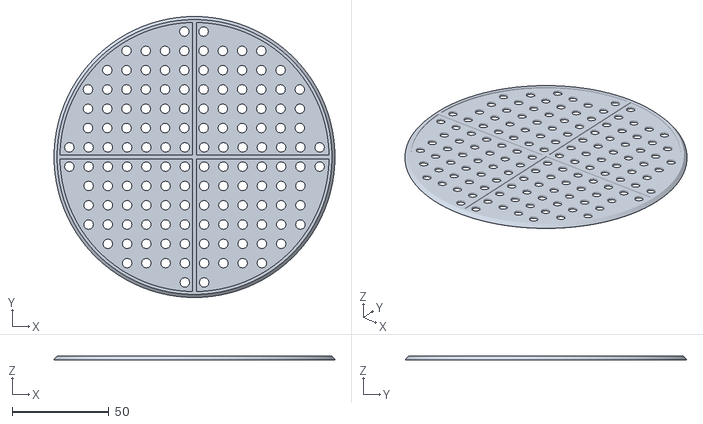
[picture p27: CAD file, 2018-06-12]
V30 moduli e griglia/stl/v30_griglia.stl
145.6 x 145.6 x 2.00

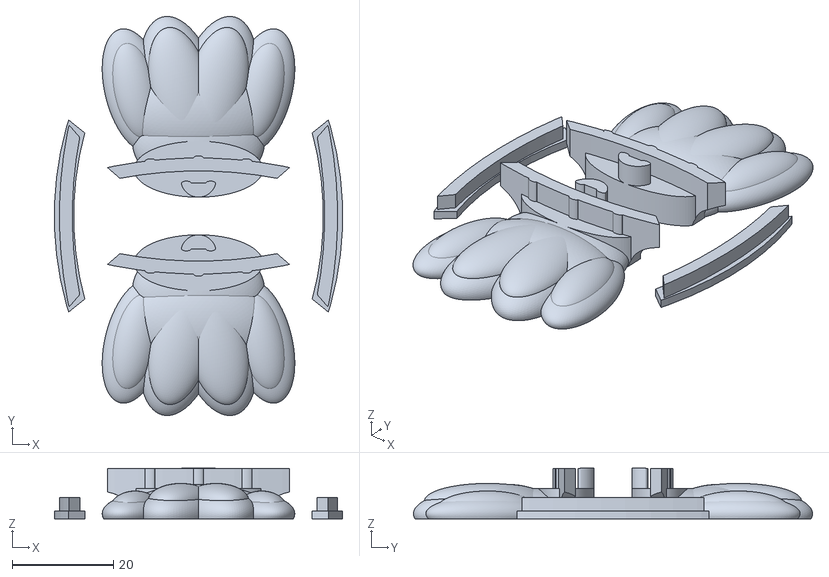
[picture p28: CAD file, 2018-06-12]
V30 serbatoio e piedini/stl/v30_zampe_accendino_piedini_colla.stl
57.0 x 79.0 x 10.00

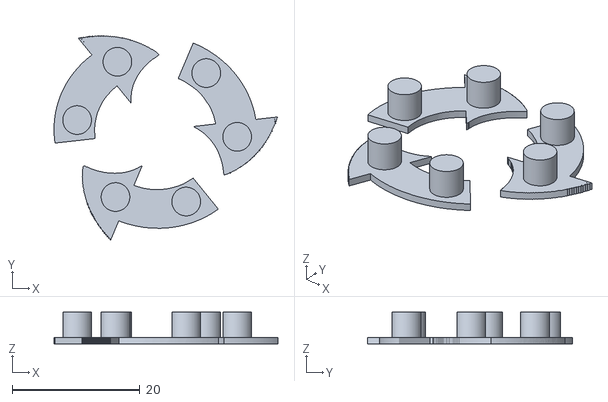
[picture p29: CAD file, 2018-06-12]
V30 cupola/stl/v30_frecce.stl
35.1 x 32.1 x 5.00

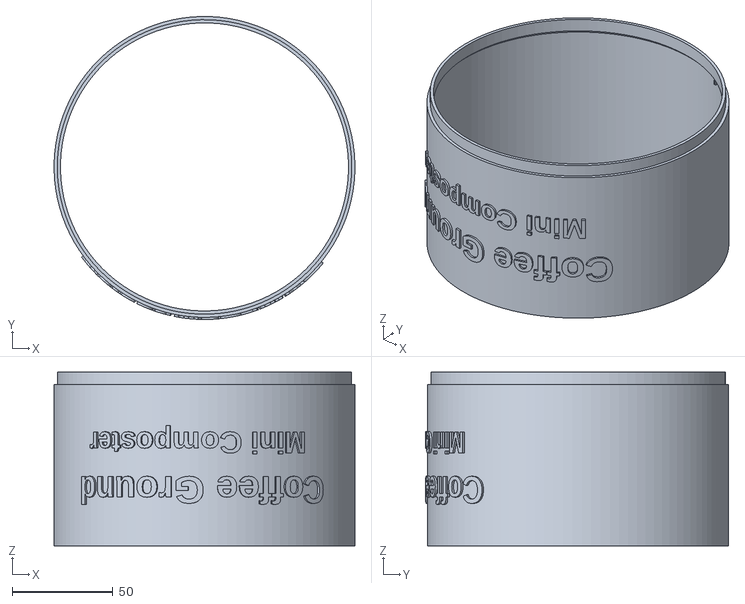
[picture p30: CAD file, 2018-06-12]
V30 moduli e griglia/stl/v30_modulo_scritta.stl
149.0 x 150.0 x 86.0

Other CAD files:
V30 serbatoio e piedini/stl/v30_colla_set_zampe_e_piedini.stl

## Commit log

2018-06-25 Test pull
    [monov30_paletta.stl]
2018-06-27 Creating folder stl
    [bicv30_cupola_e_frecce.stl, bicv30_paletta.stl, bicv30_solo_cupola.stl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]
